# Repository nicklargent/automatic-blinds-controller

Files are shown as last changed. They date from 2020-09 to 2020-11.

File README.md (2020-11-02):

# Automatic Blinds Controller

Ardunio code to control custom rig for my mini blinds.

You can find the printed parts over on [thingiverse](https://www.thingiverse.com/thing:4370318)

## Intro

My goal was to automatically open and close my office blinds in sync with daylight outside.  I was inspired by a design on thingiverse and decided to make my own controller.
I wanted to be as compact as possible which meant eliminating the control rod for the blinds.  I built a rig that attached directly to the blinds base with a minimal profile.

The design is powered by an ardunio nano powered by wall USB and triggered by a light sensor taped to the window behind the blinds.

I intended to minimize the design further with a custom board and 3D enclosure, but my reality is that this has operated flawlessly for 6 months and has been hidded behind curtains.

## Usage

1. Upon powering on, the device is in calibration mode.  The buttons are used to rotate the blinds in one direction or the other.  
2. Use the buttons to position the blinds to your preferred 'open' position.  Press both buttons together to set the position.  
3. Now use the buttons to rotate the blinds into your prefered 'closed' position and then press both buttons again.  
4. The system is now calibrated and will open / close the blinds based on the light level detected (make sure the light sensor is positioned outside of the blinds.)  
5. While in this mode, holding either button for 4 seconds will toggle the current state (open/closed).

## Parts

This design is built around an Ardunio Nano, 28BYJ-48 stepper motor, ULN2003 driver board, and common phototransistor.  

## Images

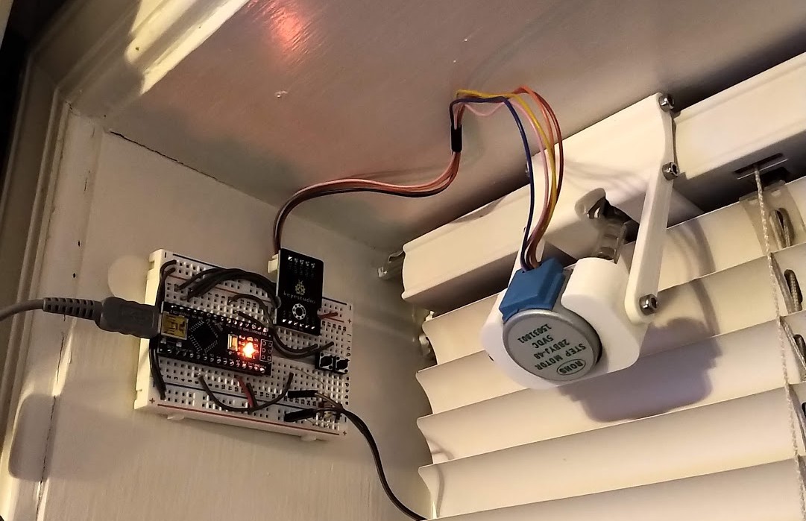
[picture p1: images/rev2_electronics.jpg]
Project Photo


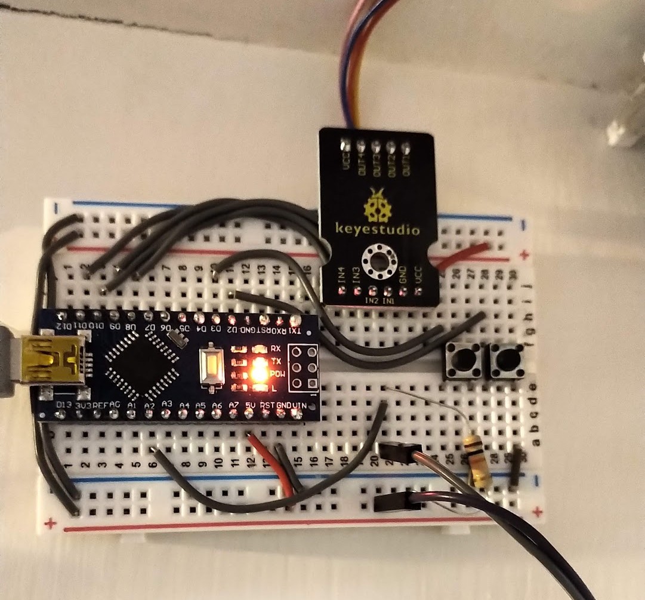
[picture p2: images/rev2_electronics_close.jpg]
Closeup


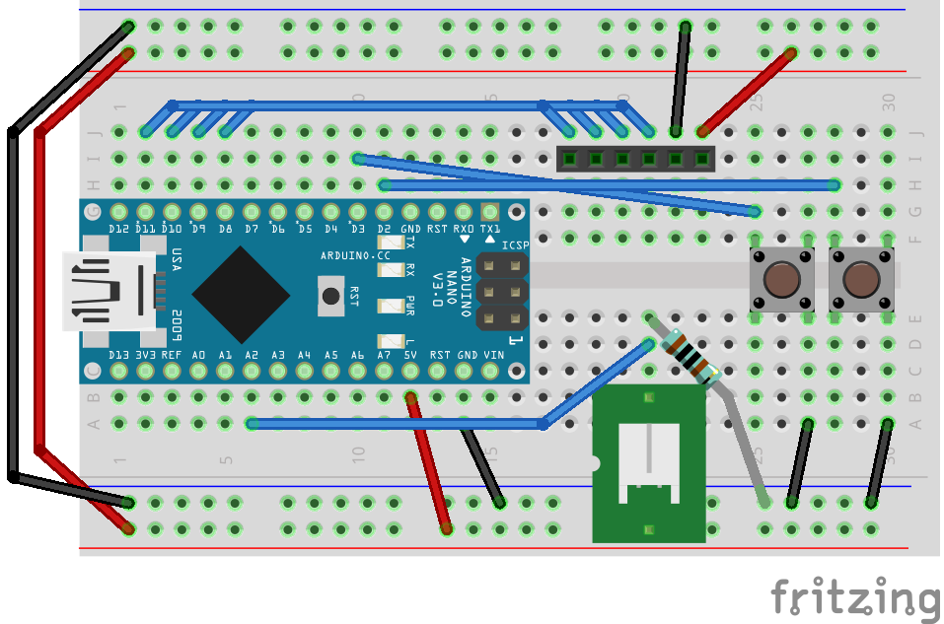
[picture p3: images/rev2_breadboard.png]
Fritz


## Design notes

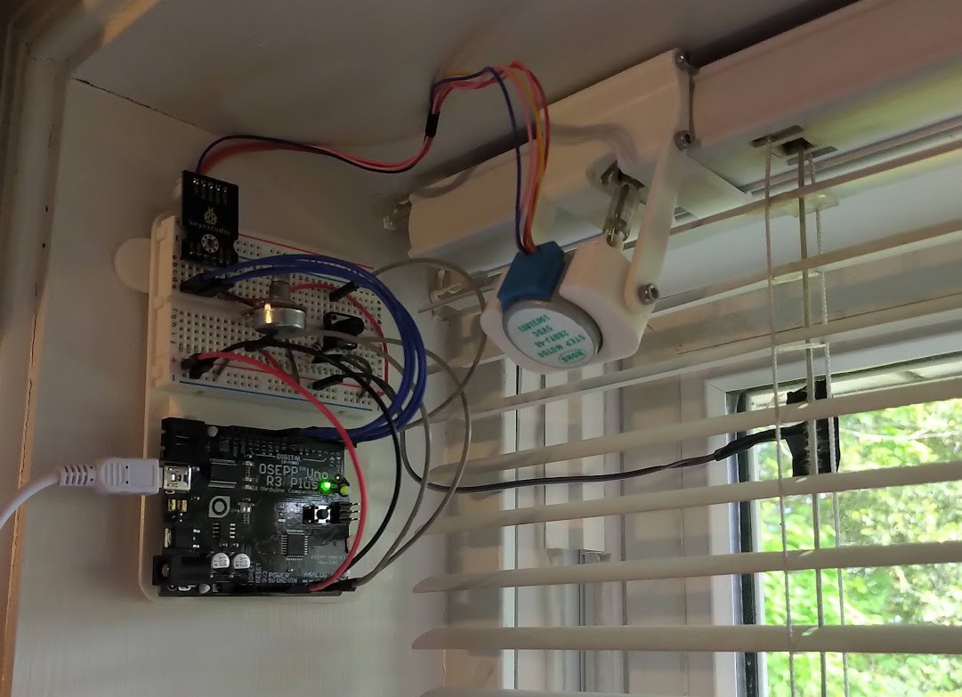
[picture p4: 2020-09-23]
images/rev1_electronics.jpg

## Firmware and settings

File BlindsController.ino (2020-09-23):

#include <Stepper.h>

// change this to the number of steps on your motor
#define STEPS_PER_REV 2038 

const int sensorMin = 370;
const int sensorMax = 1020;
const int PHOTOCELL_PIN = A2;
const int BUTTON1_PIN = 2;
const int BUTTON2_PIN = 3;

#define TRANSITION_LEVEL 10

// create an instance of the stepper class, specifying
// the number of steps of the motor and the pins it's
// attached to
Stepper stepper(STEPS_PER_REV, 8, 10, 9, 11);
bool blindsOpen = false;
bool blindOverride = false;
int trendCount = 0;

int stepCount = 0;  // number of steps the motor has taken
bool stepCountSet = false;

int mode = 1;

void setup() {  
  Serial.begin(9600);

  stepper.setSpeed(10);

  pinMode(LED_BUILTIN, OUTPUT);
  pinMode(BUTTON1_PIN, INPUT_PULLUP);
  pinMode(BUTTON2_PIN, INPUT_PULLUP);
  
  blink_ok();
}


void blink_ok() {
  for (int i = 0; i<2; i++) {
    digitalWrite(LED_BUILTIN, HIGH);
    delay(5);
    digitalWrite(LED_BUILTIN, LOW);
    delay(5);    
    digitalWrite(LED_BUILTIN, HIGH);
    delay(5);
    digitalWrite(LED_BUILTIN, LOW);
    delay(100);
  }
}

void motorOff() {
  digitalWrite(8,LOW);
  digitalWrite(9,LOW);
  digitalWrite(10,LOW);
  digitalWrite(11,LOW);
}

void openBlinds() {
  Serial.println("Opening Blinds...");
  stepper.step(-stepCount);
  motorOff();
  blindsOpen = true;
  trendCount = 0;
}

void closeBlinds() {
  Serial.println("Closing Blinds...");
  stepper.step(stepCount);
  motorOff();
  blindsOpen = false;
  trendCount = 0;
}


// direct control of blinds with the two buttons.
// Move blinds to the open position and press both buttons to reset step count.
// Move blinds to the closed position and press both buttons to set step count.
// Moves into mode2 after second button..
void mode1_loop() {
  // read the button states:
  int button1 = digitalRead(BUTTON1_PIN);
  int button2 = digitalRead(BUTTON2_PIN);

  Serial.print("MODE 1:  B1: ");
  Serial.print(button1); Serial.print("   B2: ");
  Serial.print(button2); Serial.print("   STEP_CT: ");
  Serial.println(stepCount);

  // set the motor speed:
  if (button1 == LOW && button2 == HIGH) {
    stepCount += (STEPS_PER_REV / 100);
    stepper.step(STEPS_PER_REV / 100);
  } else if (button1 == HIGH && button2 == LOW) {
    stepCount += (STEPS_PER_REV / -100);
    stepper.step(STEPS_PER_REV / -100);
  } else {
    motorOff();

    if (button1 == LOW && button2 == LOW) {
      blink_ok();
      if (!stepCountSet) {
        Serial.println("Step count reset");
        stepCount = 0;
        stepCountSet = true;
        delay(2000);
        blink_ok();
      } else {
        Serial.println("Calibration complete.");
        mode = 2;
        delay(500);
        blink_ok();
      }
    }
    
    delay(20);
  }
}


void mode2_loop() {
  int button1 = digitalRead(BUTTON1_PIN);
  int button2 = digitalRead(BUTTON2_PIN);
  
  int analogValue = analogRead(PHOTOCELL_PIN);
  int value = map(analogValue, sensorMin, sensorMax, 0, 100);
  Serial.print("MODE 2:  ");
  if (blindsOpen)
    Serial.print("OPEN  ");
  else
    Serial.print("CLOSED  ");
  if (blindOverride)
    Serial.print(" (OVERRIDE) ");
  Serial.print("  Light Level: "); Serial.print(analogValue);  Serial.print("  Adjusted: ");
  Serial.print(value);  Serial.print("   Trend: ");
  Serial.println(trendCount);

  if (button1 == LOW || button2 == LOW) {
    blindOverride = !blindOverride;
    blink_ok();
    delay(1000);
    if (blindsOpen)
      closeBlinds();
    else
      openBlinds();
  }
  
  if (!blindOverride) {
    if (blindsOpen) {
      if (value < TRANSITION_LEVEL)
        trendCount ++;
      else
        trendCount = 0;
  
      if (trendCount >= 5) {
        closeBlinds();
      }
    } else {
      if (value > TRANSITION_LEVEL)
        trendCount ++;
      else
        trendCount = 0;
  
      if (trendCount >= 5) {
        openBlinds();
      }
    }
  }
  
  delay (1000);
}


void loop() {
  switch (mode) {
    case 1:
      mode1_loop();
      break;
    case 2:
      mode2_loop();
      break;
  }
}
